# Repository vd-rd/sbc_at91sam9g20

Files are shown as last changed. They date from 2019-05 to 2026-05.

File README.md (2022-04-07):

# Microchip AT91SAM9G20

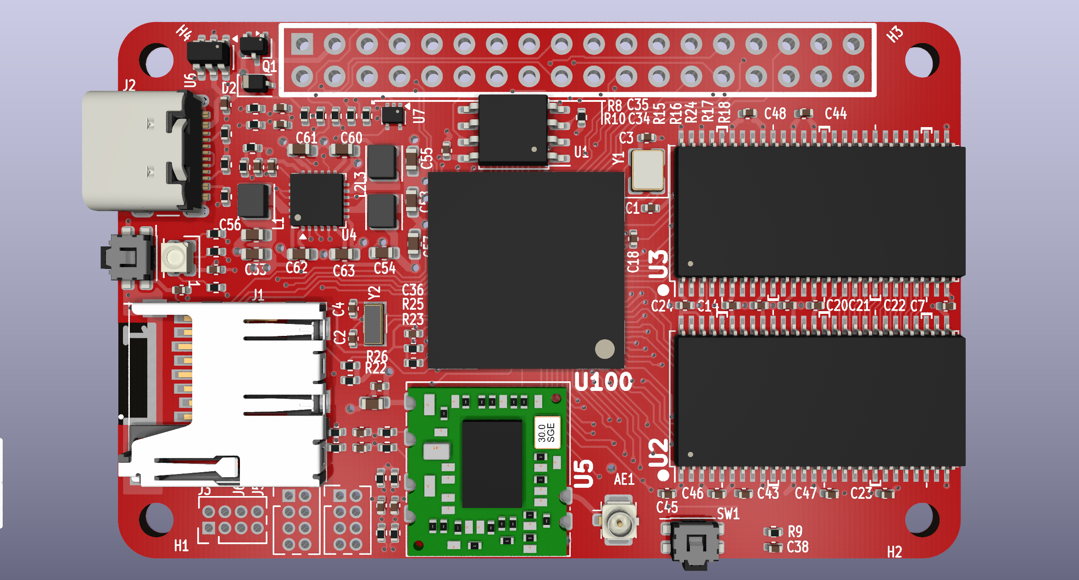
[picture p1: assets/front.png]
board_render


## Description
 The follow-up to my previous [SBC based on AT91SAM9260](https://github.com/vd-rd/sbc_at91sam9260), enhancing the board specs in computing power and flexibility. The board is smaller 60x40mm now (SAM9260 was 80x40mm) while keeping the same amount of supported RAM and interfaces. AT91SAM9G20 boosts core speed to 400MHz and bus speed to 133MHz.
 
Board overview (draft):
[TBD]

### Features

| Characteristic | Description |
| --- | --- |
| Dimensions | 60mm x 40mm |
| Processor | AT91SAM9G20 - ARM926EJ @ 400MHz |
| Oscillators |  18.432MHz main clock, 32.768kHz RTC |
| RAM | SDRAM 128MB max (2x512Mbit modules) |
| Storage | microSD |
| USB | 1 microUSB client, 2 USB Host|
| Ethernet | RMII header |
| WiFi/BT | N/A |
| Supply | USB 5V, ACIN 5V |

Common interfaces such as I2C, SPI, UART and GPIO are exposed on the header.

### Building and flashing

Build U-Boot and Linux kernel + rootFS - TBD

Flash to SDCard - TBD

### Resources

You can find all necesary information to build or evaluate the module here:
   - [Fabrication files](https://github.com/vd-rd/sbc_alw_a13/releases)

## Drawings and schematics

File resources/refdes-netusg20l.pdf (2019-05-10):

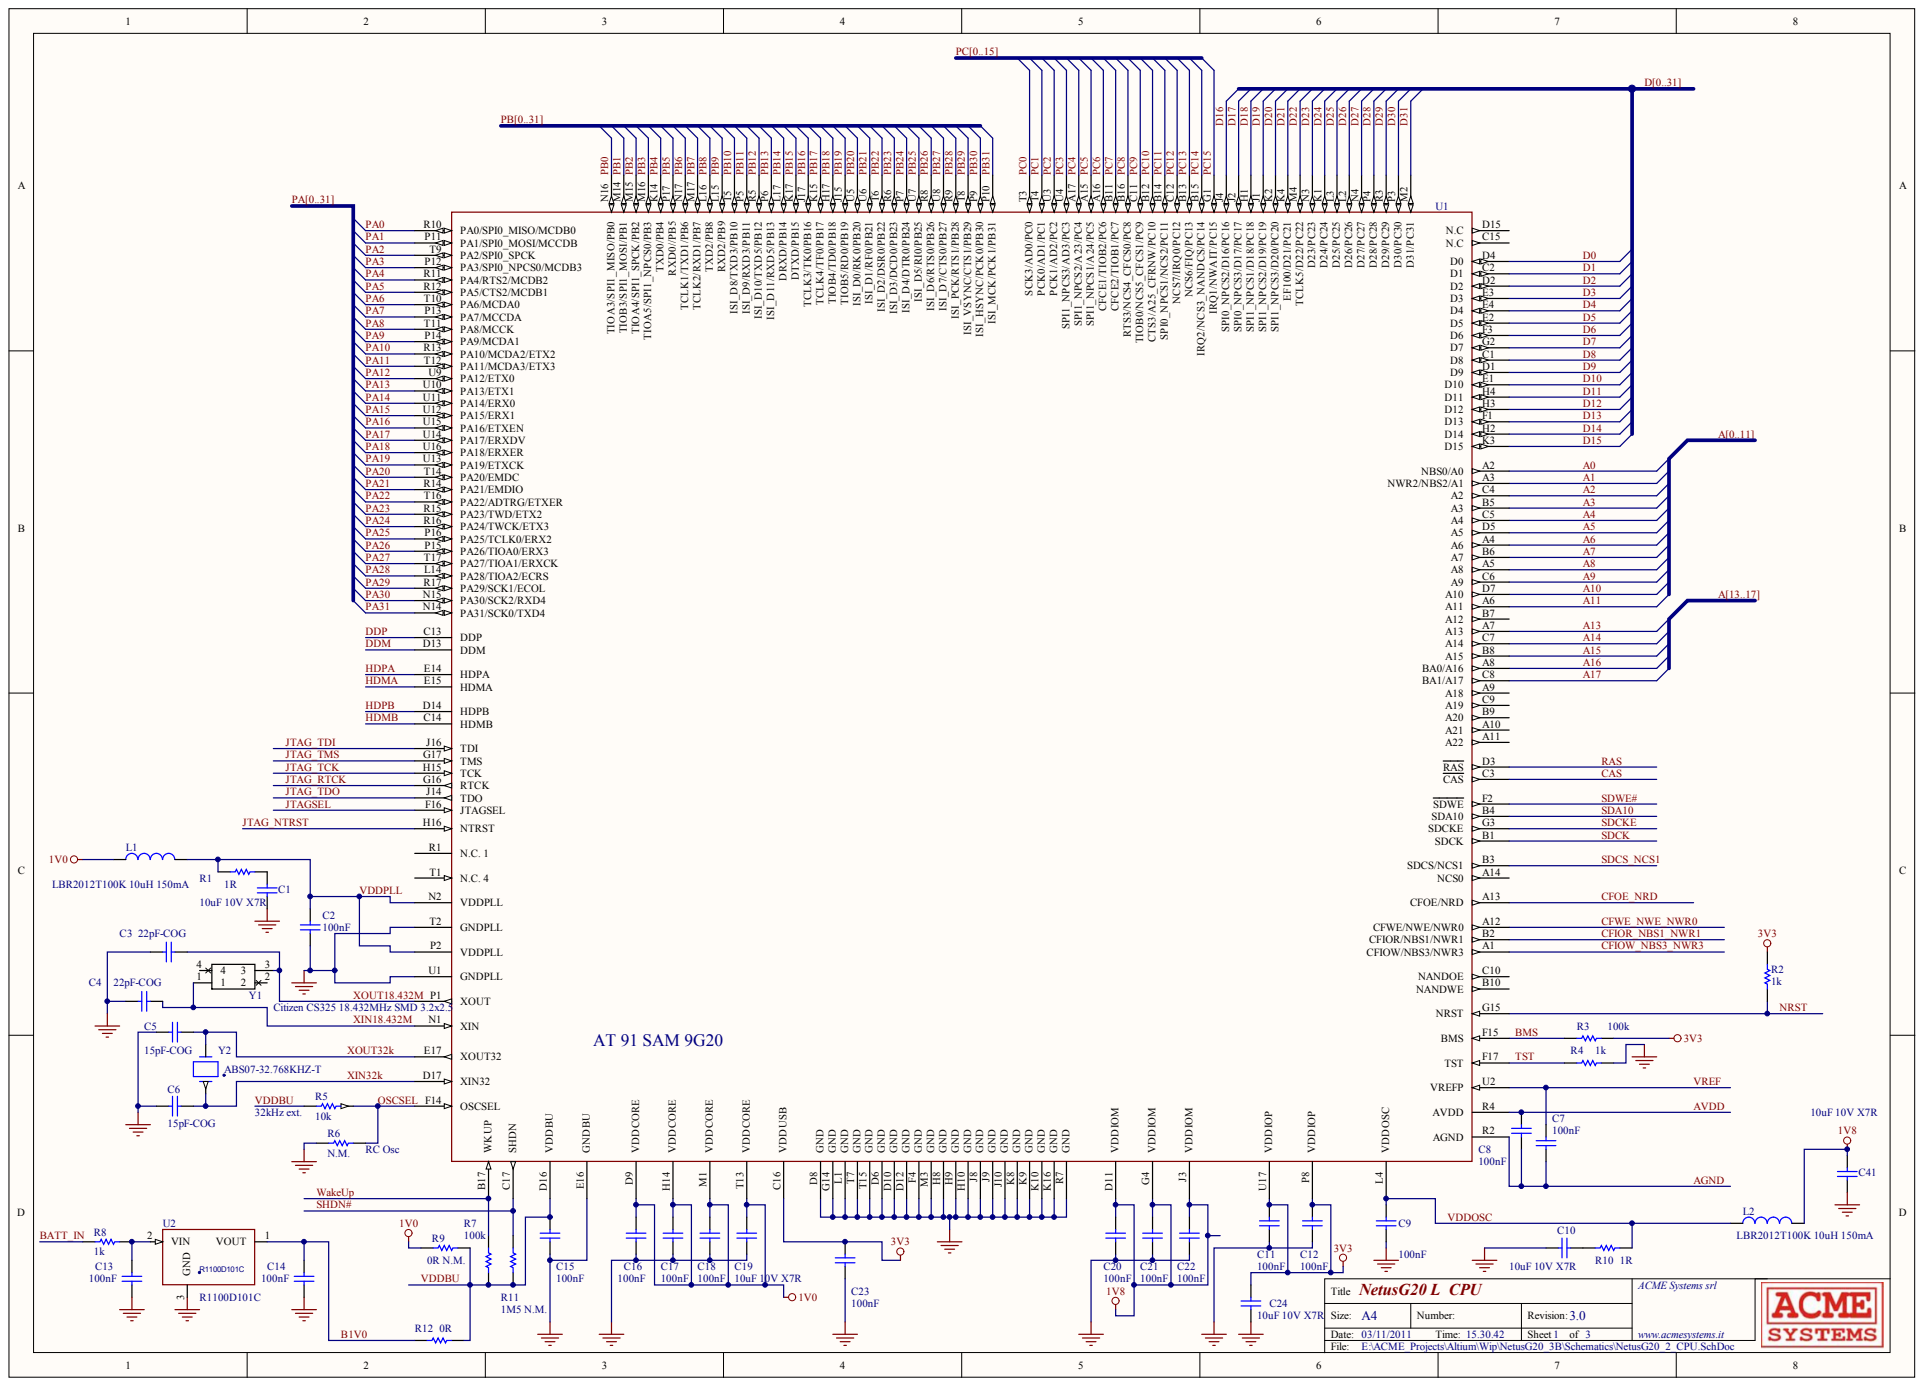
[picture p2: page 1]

3.2 x 2 . | 5 XIN N1

C5 15p | | | XOUT3 2 k | E 1 7

S 0 7 -3 2.7 6 8 KHZ -T XIN 3 2 k

VDDBU OSCSEL | F 1 4

C2 | | NetusG20 L CPU T itl | A CME Syste m s s r l www. a c esyst e ms.it

i z : A4 | Numb er: | Re v o n

Date ime . | | f

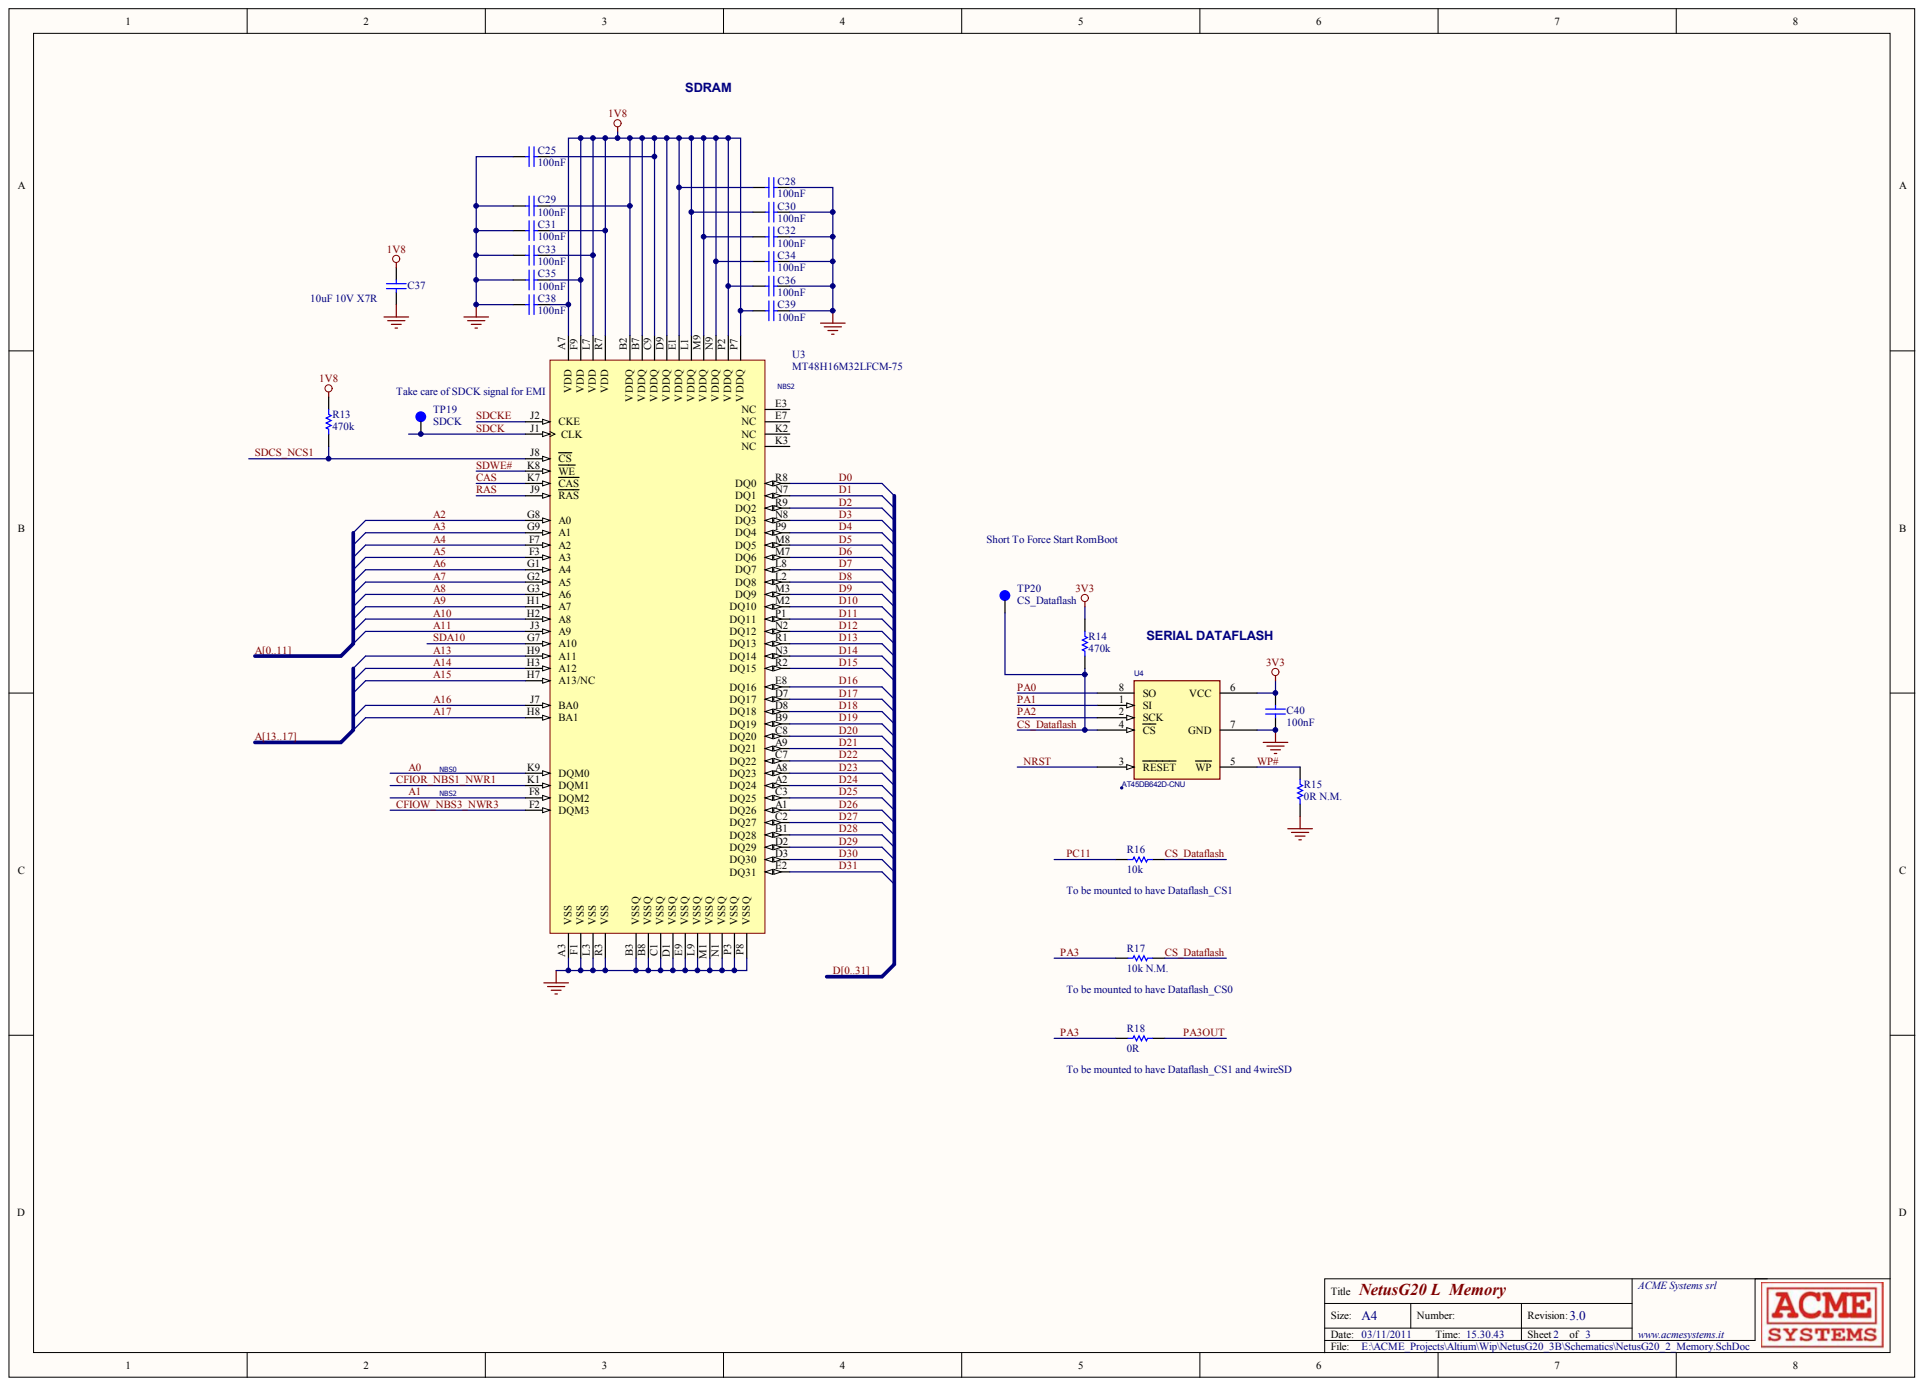
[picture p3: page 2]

VSSQ N1 VDDQ N9 VDDQ P2 VSSQ P3 VDDQ P7

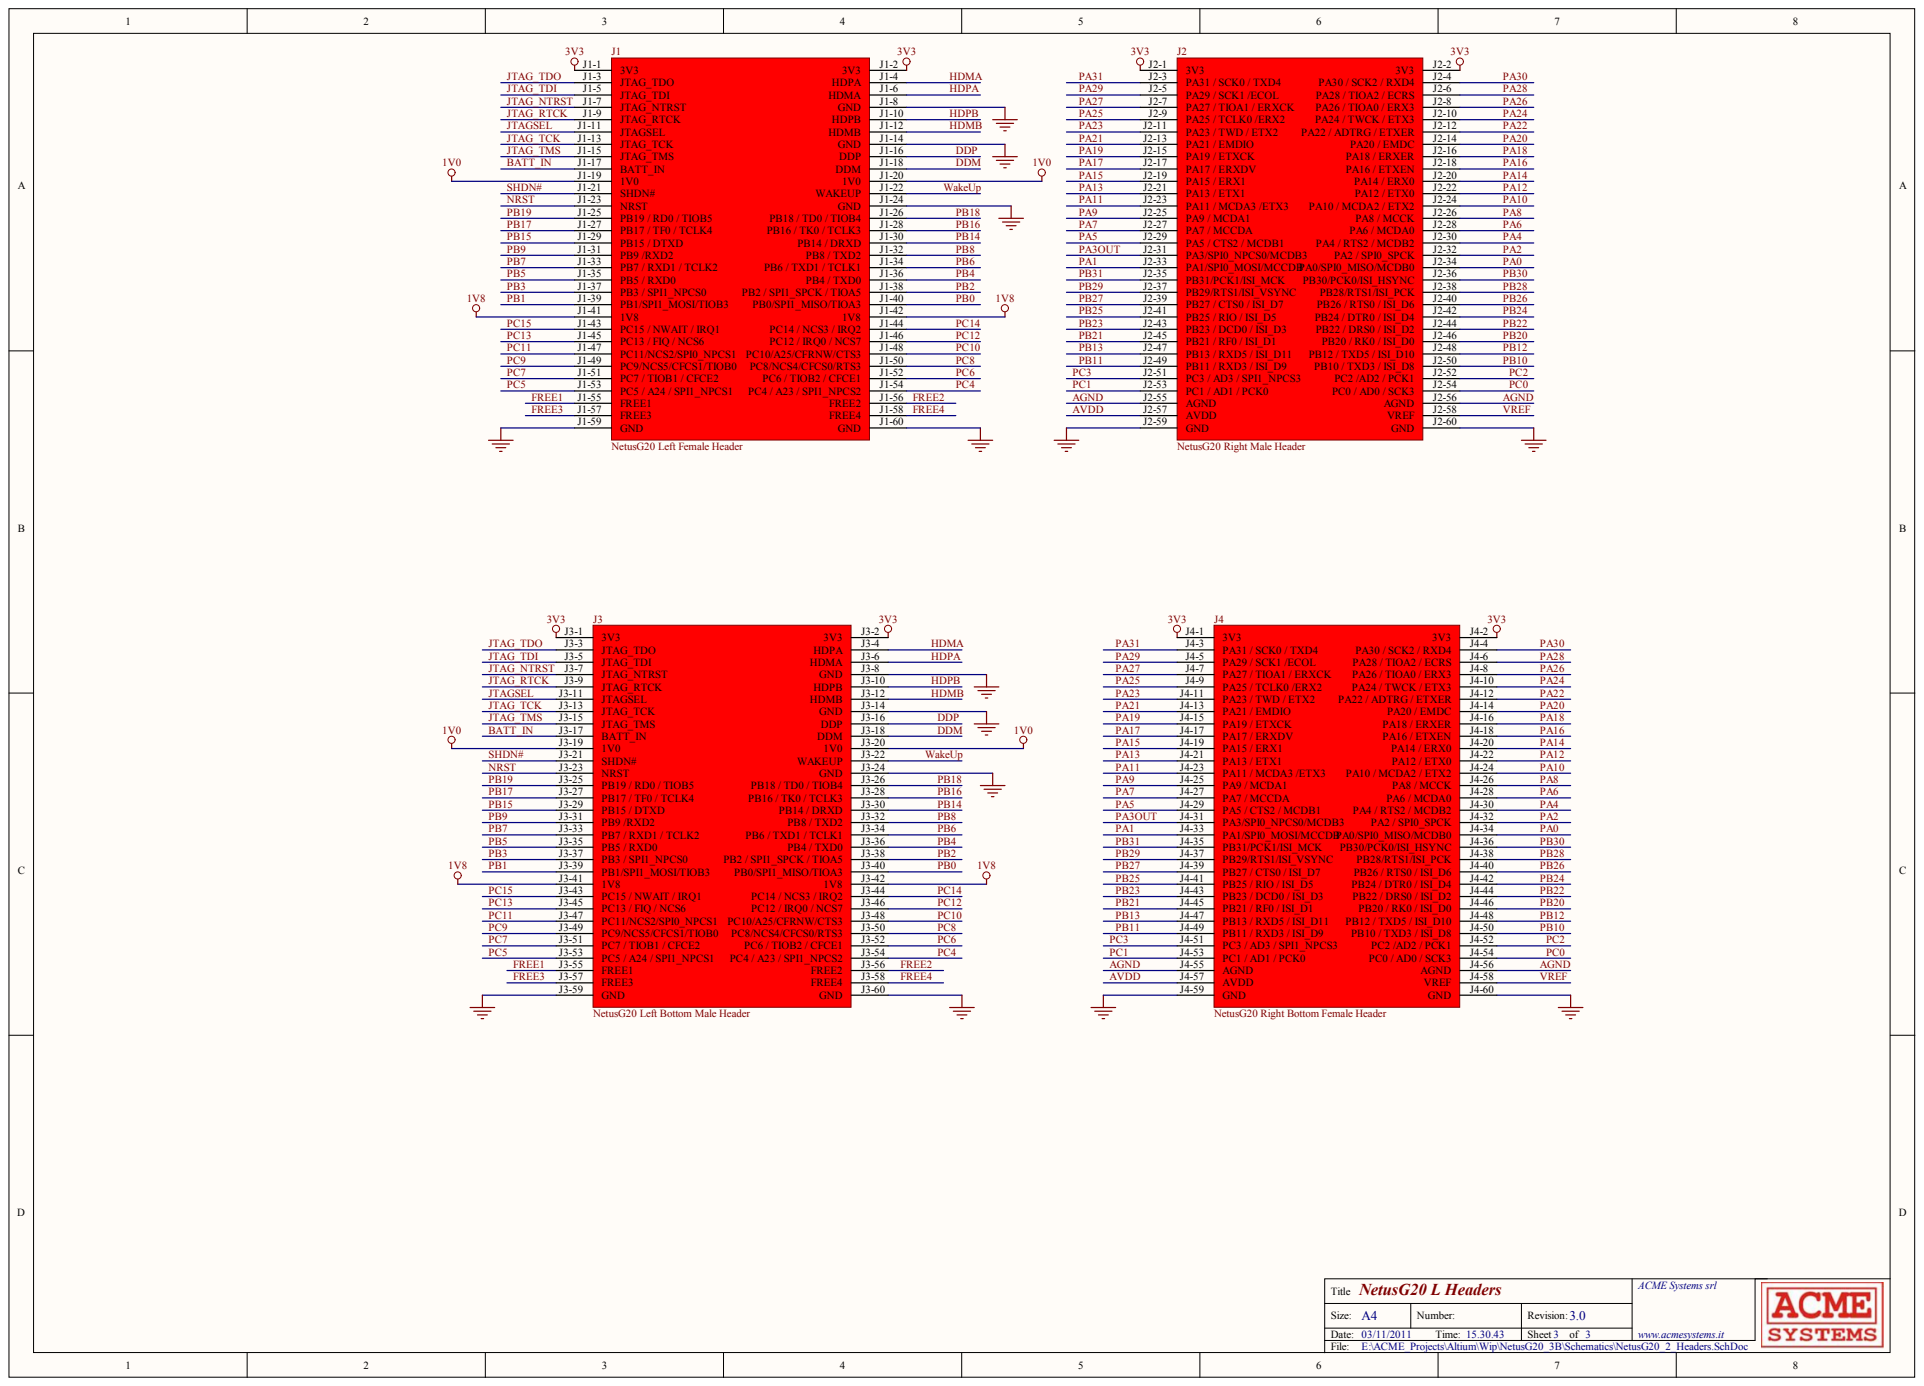
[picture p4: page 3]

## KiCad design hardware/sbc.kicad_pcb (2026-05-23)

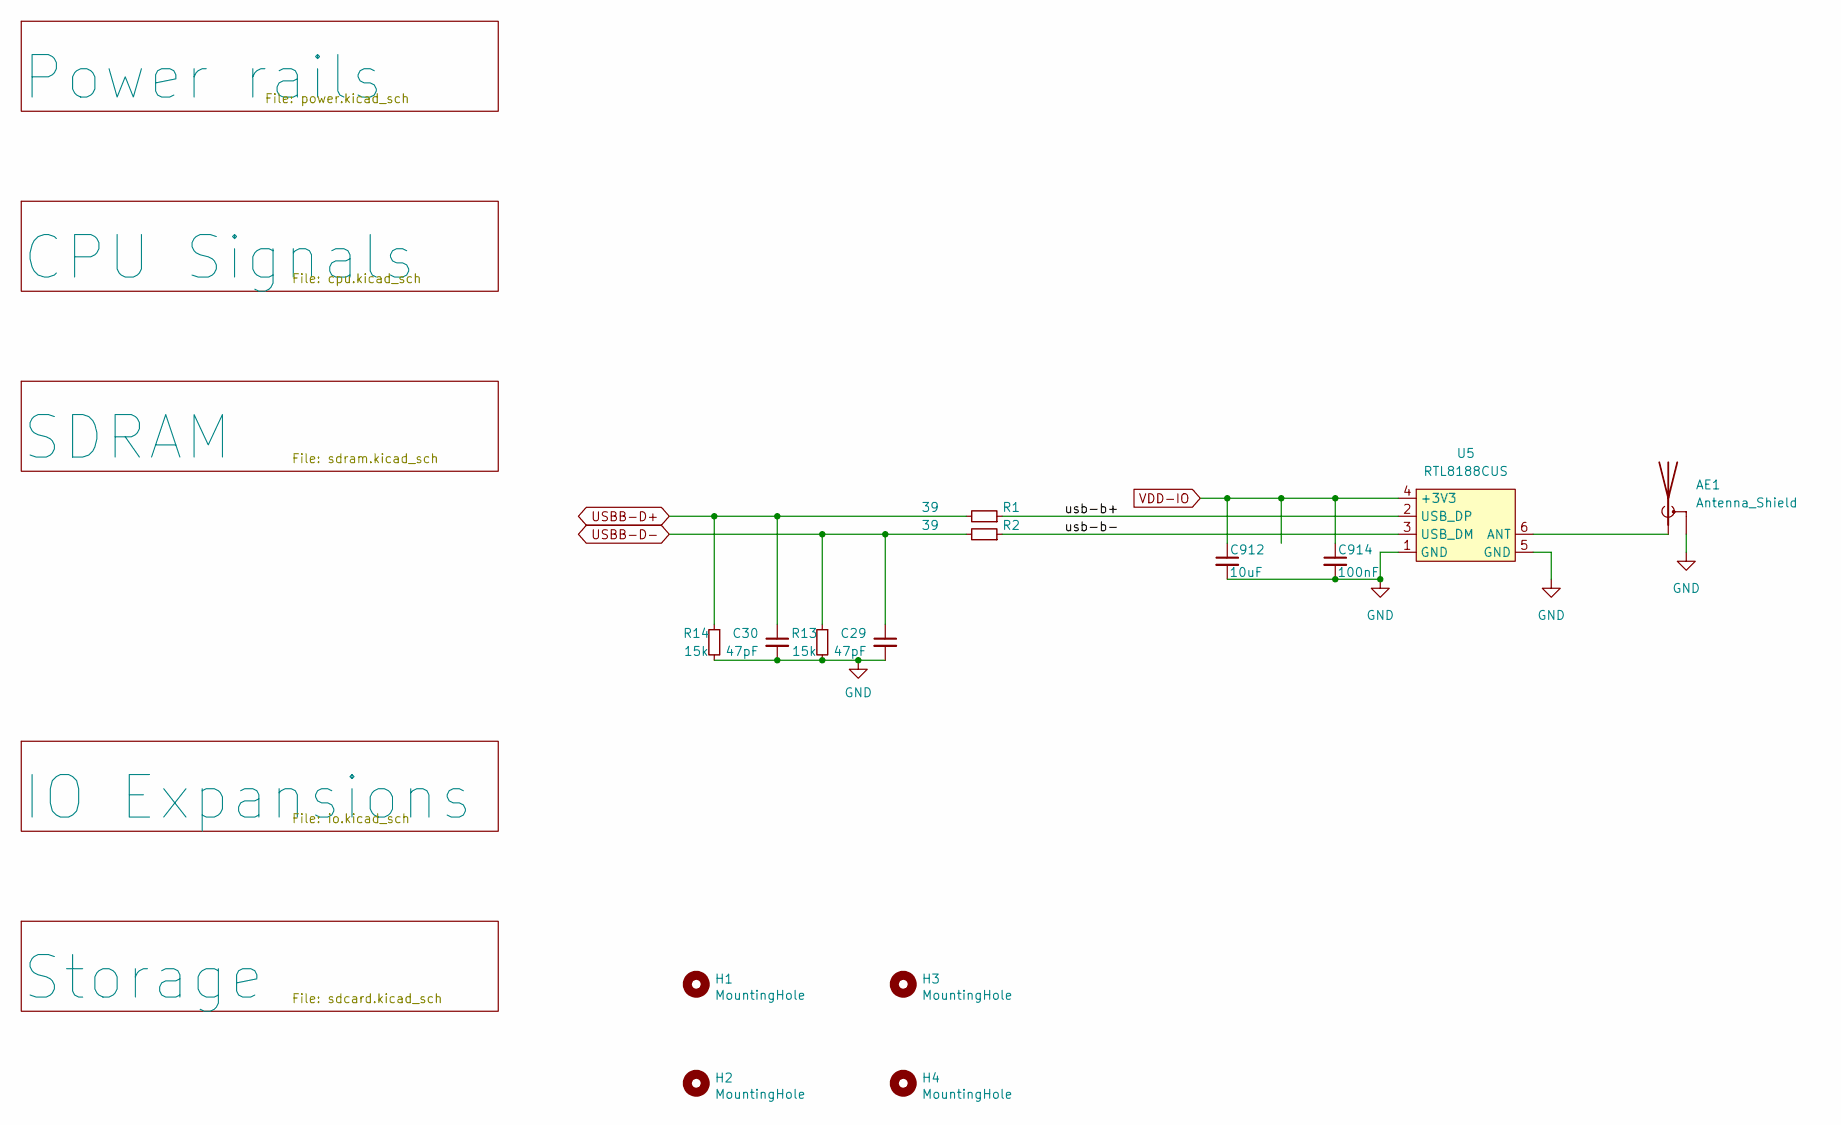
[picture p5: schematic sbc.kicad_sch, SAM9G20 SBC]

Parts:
AE1: Antenna_Shield; U.FL_Hirose_U.FL-R-SMT-1_Vertical
C29, C30: 47pF; C_0402_1005Metric
C912: 10uF; C_0603_1608Metric
C914: 100nF; C_0402_1005Metric
H1, H2, H3, H4: MountingHole; MountingHole_2.7mm_M2.5_DIN965
R1, R2: 39; R_0402_1005Metric
R13, R14: 15k; R_0402_1005Metric
U5: RTL8188CUS

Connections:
/usb-b+: R1.1, U5.2 (USB_DP)
/usb-b-: R2.1, U5.3 (USB_DM)
GND: AE1.2 (Shield), C29.2, C30.2, C912.2, C914.2, R13.2, R14.2, U5.1 (GND), U5.5 (GND); also elsewhere on the board
unnamed: AE1.1 (A), U5.6 (ANT)
USBB-D+: C30.1, R1.2, R14.1; also elsewhere on the board
USBB-D-: C29.1, R2.2, R13.1; also elsewhere on the board
VDD-IO: C912.1, C914.1, U5.4 (+3V3); also elsewhere on the board

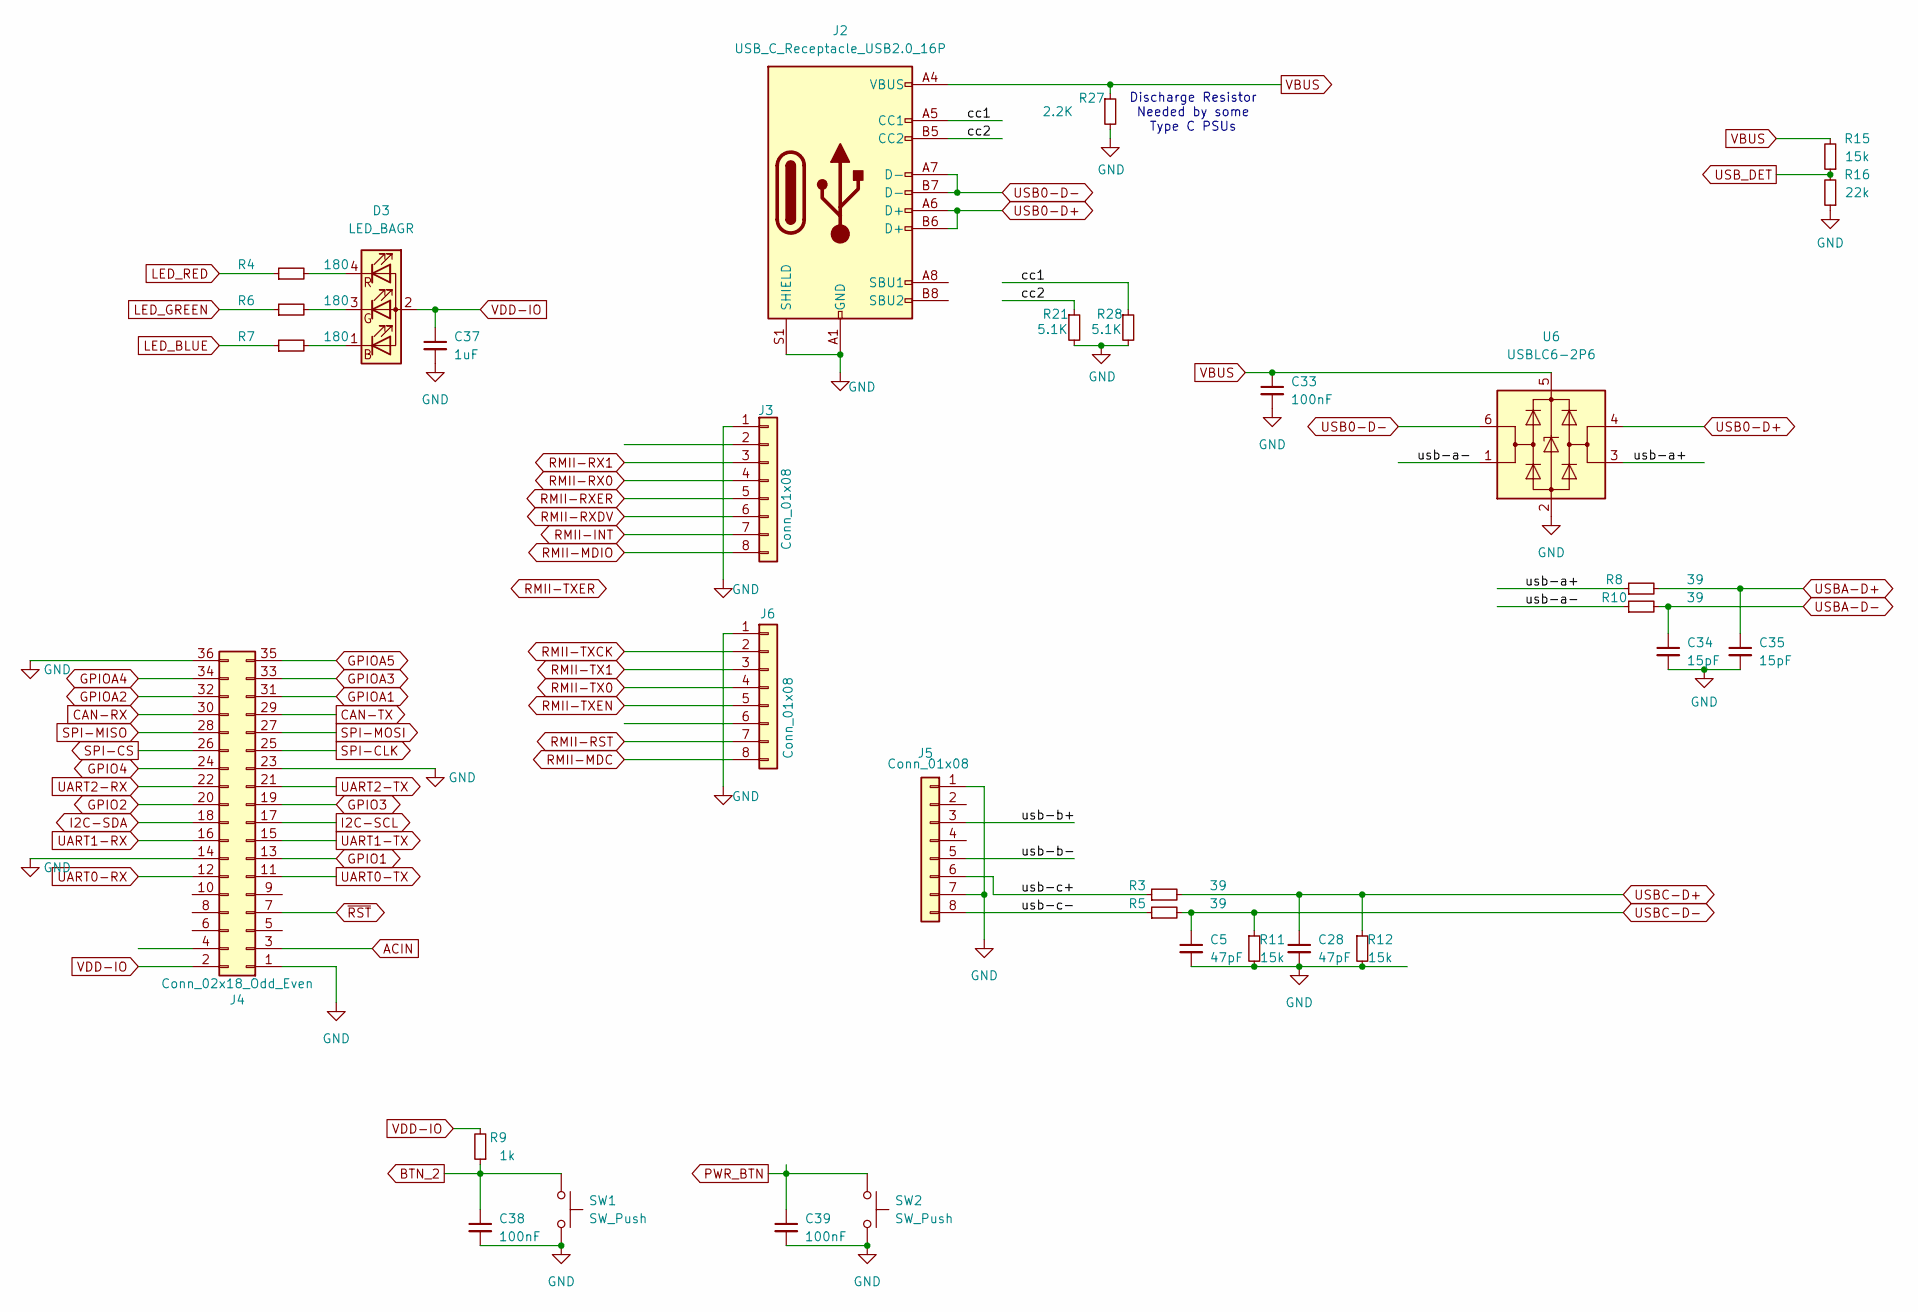
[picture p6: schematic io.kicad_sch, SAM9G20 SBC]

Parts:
C5, C28: 47pF; C_0402_1005Metric
C33, C38, C39: 100nF; C_0402_1005Metric
C34, C35: 15pF; C_0402_1005Metric
C37: 1uF; C_0402_1005Metric
D3: LED_BAGR; LED_RGB_Optosupply_OSTB0805C1E-A-0.8T
J2: USB_C_Receptacle_USB2.0_16P; USB_C_Receptacle_GCT_USB4105-xx-A_16P_TopMnt_Horizontal
J3, J5, J6: Conn_01x08; PinHeader_2x04_P1.27mm_Vertical
J4: Conn_02x18_Odd_Even; PinHeader_2x18_P2.54mm_Vertical
R3, R5, R8, R10: 39; R_0402_1005Metric
R4, R6, R7: 180; R_0402_1005Metric
R9: 1k; R_0402_1005Metric
R11, R12, R15: 15k; R_0402_1005Metric
R16: 22k; R_0402_1005Metric
R21, R28: 5.1K; R_0402_1005Metric; Part Description Resistor 2.2K M1005 1% 63mW
R27: 2.2K; R_0402_1005Metric; Part Description Resistor 2.2K M1005 1% 63mW
SW1, SW2: SW_Push; SW_SPST_EVQP7C
U6: USBLC6-2P6; SOT-23-6

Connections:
/IO Expansions/cc1: J2.A5 (CC1), R28.1
/IO Expansions/cc2: J2.B5 (CC2), R21.1
/IO Expansions/usb-a+: R8.1, U6.3 (I/O2)
/IO Expansions/usb-a-: R10.1, U6.1 (I/O1)
/IO Expansions/usb-b+: J5.3
/IO Expansions/usb-b-: J5.5
/IO Expansions/usb-c+: J5.6, R3.1
/IO Expansions/usb-c-: J5.8, R5.1
ACIN: J4.3; also elsewhere on the board
BTN_2: C38.1, R9.1, SW1.1; also elsewhere on the board
CAN-RX: J4.30
CAN-TX: J4.29
GND: C5.2, C28.2, C33.2, C34.2, C35.2, C37.2, C38.2, C39.2, J2.A1 (GND), J2.A12 (GND), J2.B1 (GND), J2.B12 (GND), J2.S1 (SHIELD), J3.1, J4.1, J4.14, J4.23, J4.36, J5.1, J5.7, J6.1, R11.2, R12.2, R16.1, R21.2, R27.2, R28.2, SW1.2, SW2.2, U6.2 (GND); also elsewhere on the board
GPIO1: J4.13; also elsewhere on the board
GPIO2: J4.20; also elsewhere on the board
GPIO3: J4.19; also elsewhere on the board
GPIO4: J4.24; also elsewhere on the board
GPIOA1: J4.31; also elsewhere on the board
GPIOA2: J4.32; also elsewhere on the board
GPIOA3: J4.33; also elsewhere on the board
GPIOA4: J4.34; also elsewhere on the board
GPIOA5: J4.35
I2C-SCL: J4.17; also elsewhere on the board
I2C-SDA: J4.18; also elsewhere on the board
LED_BLUE: R7.1; also elsewhere on the board
LED_GREEN: R6.1; also elsewhere on the board
LED_RED: R4.1; also elsewhere on the board
unnamed: D3.1 (BK), R7.2
unnamed: D3.3 (GK), R6.2
unnamed: D3.4 (RK), R4.2
PWR_BTN: C39.1, SW2.1; also elsewhere on the board
RMII-INT: J3.7
RMII-MDC: J6.8; also elsewhere on the board
RMII-MDIO: J3.8; also elsewhere on the board
RMII-RST: J6.7
RMII-RX0: J3.4; also elsewhere on the board
RMII-RX1: J3.3; also elsewhere on the board
RMII-RXDV: J3.6; also elsewhere on the board
RMII-RXER: J3.5; also elsewhere on the board
RMII-TX0: J6.4; also elsewhere on the board
RMII-TX1: J6.3; also elsewhere on the board
RMII-TXCK: J6.2; also elsewhere on the board
RMII-TXEN: J6.5; also elsewhere on the board
SPI-CLK: J4.25; also elsewhere on the board
SPI-CS: J4.26; also elsewhere on the board
SPI-MISO: J4.28; also elsewhere on the board
SPI-MOSI: J4.27; also elsewhere on the board
UART0-RX: J4.12; also elsewhere on the board
UART0-TX: J4.11; also elsewhere on the board
UART1-RX: J4.16; also elsewhere on the board
UART1-TX: J4.15; also elsewhere on the board
UART2-RX: J4.22; also elsewhere on the board
UART2-TX: J4.21; also elsewhere on the board
USB0-D+: J2.A6 (D+), J2.B6 (D+), U6.4 (I/O2)
USB0-D-: J2.A7 (D-), J2.B7 (D-), U6.6 (I/O1)
USBA-D+: C35.1, R8.2; also elsewhere on the board
USBA-D-: C34.1, R10.2; also elsewhere on the board
USBC-D+: C28.1, R3.2, R12.1; also elsewhere on the board
USBC-D-: C5.1, R5.2, R11.1; also elsewhere on the board
USB_DET: R15.1, R16.2; also elsewhere on the board
VBUS: C33.1, J2.A4 (VBUS), J2.A9 (VBUS), J2.B4 (VBUS), J2.B9 (VBUS), R15.2, R27.1, U6.5 (VBUS); also elsewhere on the board
VDD-IO: C37.1, D3.2 (A), J4.2, R9.2; also elsewhere on the board
~RST: J4.7; also elsewhere on the board

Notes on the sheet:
Discharge Resistor Needed by some Type C PSUs

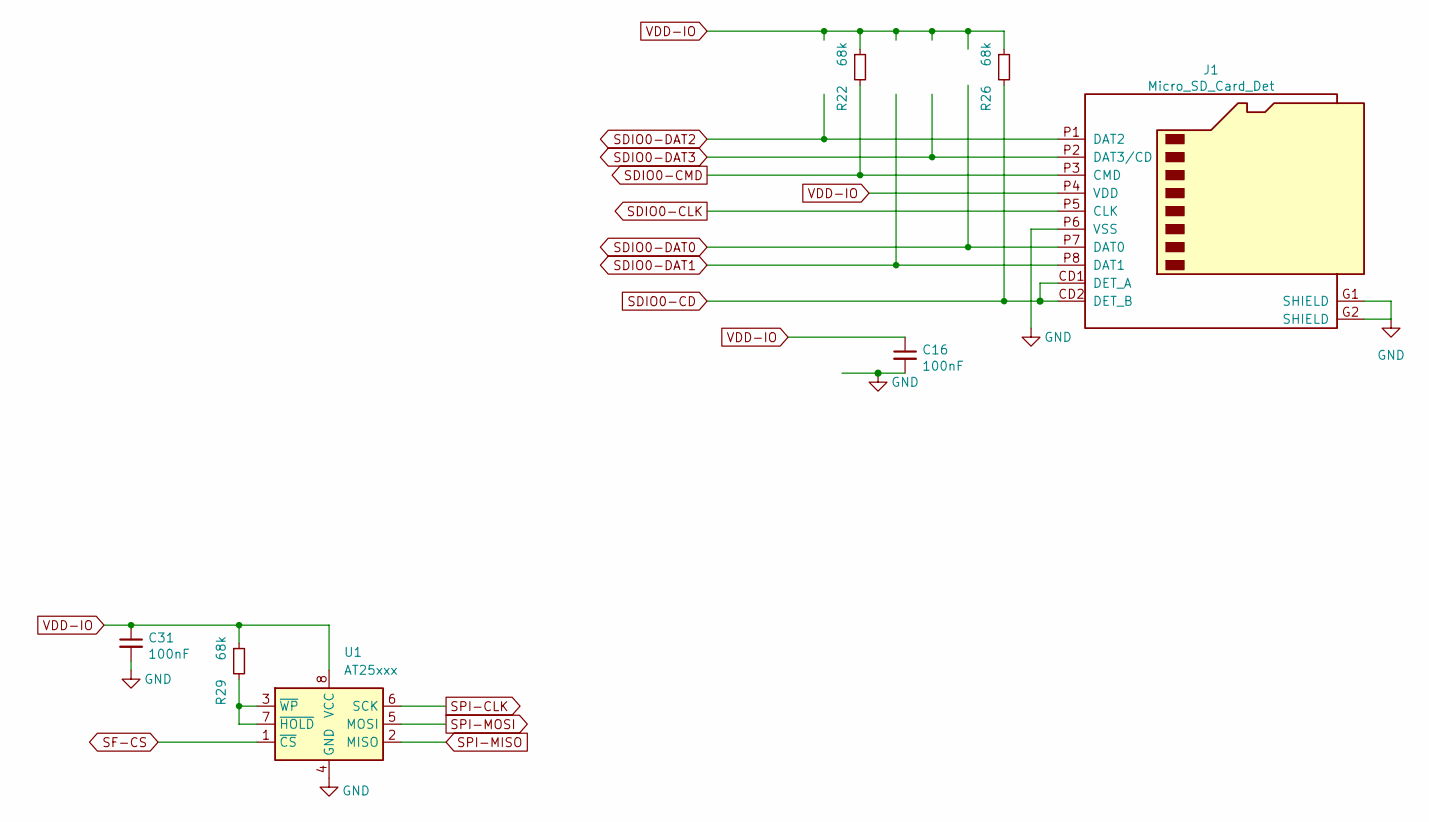
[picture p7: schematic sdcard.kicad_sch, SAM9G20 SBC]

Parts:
C16, C31: 100nF; C_0402_1005Metric
J1: Micro_SD_Card_Det; MEM20610118800A
R22, R26, R29: 68k; R_0402_1005Metric
U1: AT25xxx; SOIC-8_5.23x5.23mm_P1.27mm

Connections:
GND: C16.2, C31.2, J1.G1 (SHIELD), J1.G2 (SHIELD), J1.P6 (VSS), U1.4 (GND); also elsewhere on the board
unnamed: R29.2, U1.3 (~WP), U1.7 (~HOLD)
SDIO0-CD: J1.CD1 (DET_A), J1.CD2 (DET_B), R26.2; also elsewhere on the board
SDIO0-CLK: J1.P5 (CLK); also elsewhere on the board
SDIO0-CMD: J1.P3 (CMD), R22.2; also elsewhere on the board
SDIO0-DAT0: J1.P7 (DAT0); also elsewhere on the board
SDIO0-DAT1: J1.P8 (DAT1); also elsewhere on the board
SDIO0-DAT2: J1.P1 (DAT2); also elsewhere on the board
SDIO0-DAT3: J1.P2 (DAT3/CD); also elsewhere on the board
SF-CS: U1.1 (~CS); also elsewhere on the board
SPI-CLK: U1.6 (SCK); also elsewhere on the board
SPI-MISO: U1.2 (MISO); also elsewhere on the board
SPI-MOSI: U1.5 (MOSI); also elsewhere on the board
VDD-IO: C16.1, C31.1, J1.P4 (VDD), R22.1, R26.1, R29.1, U1.8 (VCC); also elsewhere on the board

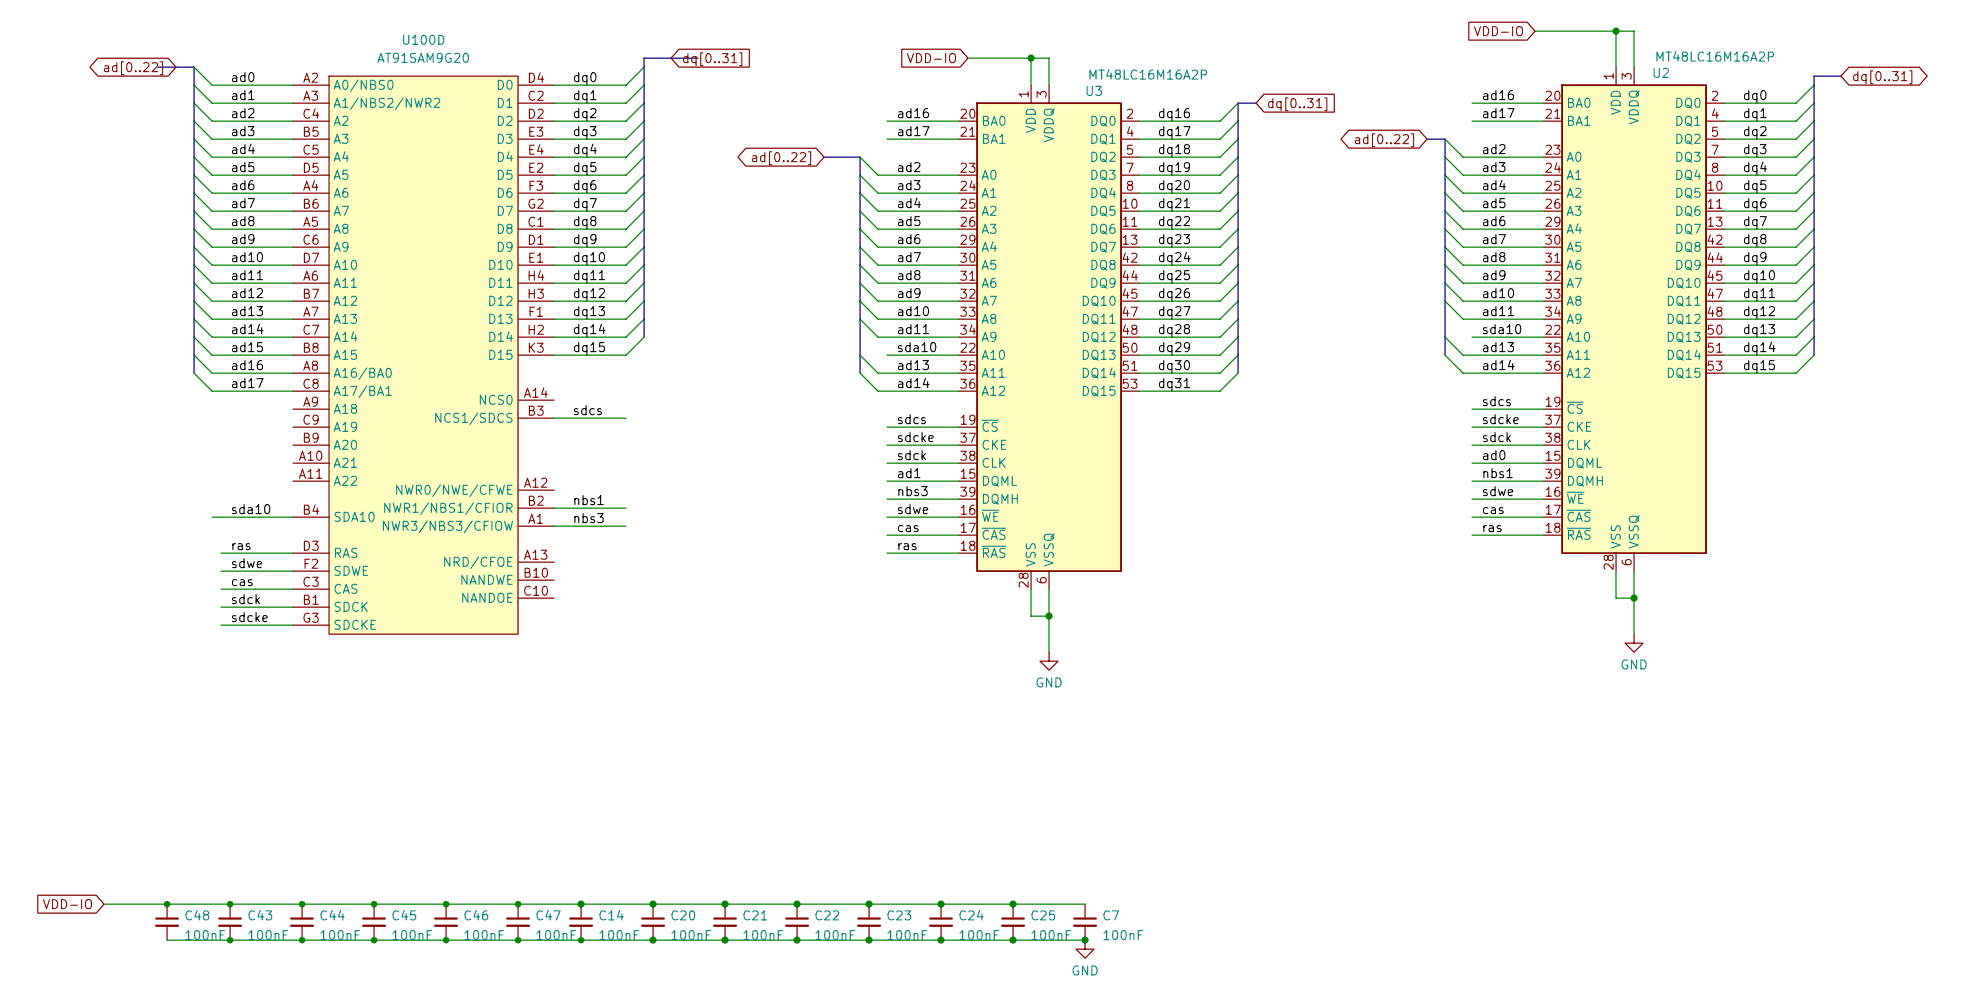
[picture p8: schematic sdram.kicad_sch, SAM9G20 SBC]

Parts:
C7, C14, C20, C21, C22, C23, C24, C25, C43, C44, C45, C46, C47, C48: 100nF; C_0402_1005Metric
U2, U3: MT48LC16M16A2P; TSOP-II-54_22.2x10.16mm_P0.8mm
U100: AT91SAM9G20; AT91SAM9G10

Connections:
/SDRAM/cas: U2.17 (~CAS), U3.17 (~CAS), U100.C3 (CAS)
/SDRAM/nbs1: U2.39 (DQMH), U100.B2 (NWR1/NBS1/CFIOR)
/SDRAM/nbs3: U3.39 (DQMH), U100.A1 (NWR3/NBS3/CFIOW)
/SDRAM/ras: U2.18 (~RAS), U3.18 (~RAS), U100.D3 (RAS)
/SDRAM/sda10: U2.22 (A10), U3.22 (A10), U100.B4 (SDA10)
/SDRAM/sdck: U2.38 (CLK), U3.38 (CLK), U100.B1 (SDCK)
/SDRAM/sdcke: U2.37 (CKE), U3.37 (CKE), U100.G3 (SDCKE)
/SDRAM/sdcs: U2.19 (~CS), U3.19 (~CS), U100.B3 (NCS1/SDCS)
/SDRAM/sdwe: U2.16 (~WE), U3.16 (~WE), U100.F2 (SDWE)
GND: C7.2, C14.2, C20.2, C21.2, C22.2, C23.2, C24.2, C25.2, C43.2, C44.2, C45.2, C46.2, C47.2, C48.2, U2.6 (VSSQ), U2.12 (VSSQ), U2.28 (VSS), U2.41 (VSS), U2.46 (VSSQ), U2.52 (VSSQ), U2.54 (VSS), U3.6 (VSSQ), U3.12 (VSSQ), U3.28 (VSS), U3.41 (VSS), U3.46 (VSSQ), U3.52 (VSSQ), U3.54 (VSS); also elsewhere on the board
VDD-IO: C7.1, C14.1, C20.1, C21.1, C22.1, C23.1, C24.1, C25.1, C43.1, C44.1, C45.1, C46.1, C47.1, C48.1, U2.1 (VDD), U2.3 (VDDQ), U2.9 (VDDQ), U2.14 (VDD), U2.27 (VDD), U2.43 (VDDQ), U2.49 (VDDQ), U3.1 (VDD), U3.3 (VDDQ), U3.9 (VDDQ), U3.14 (VDD), U3.27 (VDD), U3.43 (VDDQ), U3.49 (VDDQ); also elsewhere on the board
ad0: U2.15 (DQML), U100.A2 (A0/NBS0)
ad1: U3.15 (DQML), U100.A3 (A1/NBS2/NWR2)
ad2: U2.23 (A0), U3.23 (A0), U100.C4 (A2)
ad3: U2.24 (A1), U3.24 (A1), U100.B5 (A3)
ad4: U2.25 (A2), U3.25 (A2), U100.C5 (A4)
ad5: U2.26 (A3), U3.26 (A3), U100.D5 (A5)
ad6: U2.29 (A4), U3.29 (A4), U100.A4 (A6)
ad7: U2.30 (A5), U3.30 (A5), U100.B6 (A7)
ad8: U2.31 (A6), U3.31 (A6), U100.A5 (A8)
ad9: U2.32 (A7), U3.32 (A7), U100.C6 (A9)
ad10: U2.33 (A8), U3.33 (A8), U100.D7 (A10)
ad11: U2.34 (A9), U3.34 (A9), U100.A6 (A11)
ad12: U100.B7 (A12)
ad13: U2.35 (A11), U3.35 (A11), U100.A7 (A13)
ad14: U2.36 (A12), U3.36 (A12), U100.C7 (A14)
ad15: U100.B8 (A15)
ad16: U2.20 (BA0), U3.20 (BA0), U100.A8 (A16/BA0)
ad17: U2.21 (BA1), U3.21 (BA1), U100.C8 (A17/BA1)
dq0: U2.2 (DQ0), U100.D4 (D0)
dq1: U2.4 (DQ1), U100.C2 (D1)
dq2: U2.5 (DQ2), U100.D2
dq3: U2.7 (DQ3), U100.E3 (D3)
dq4: U2.8 (DQ4), U100.E4 (D4)
dq5: U2.10 (DQ5), U100.E2 (D5)
dq6: U2.11 (DQ6), U100.F3 (D6)
dq7: U2.13 (DQ7), U100.G2 (D7)
dq8: U2.42 (DQ8), U100.C1 (D8)
dq9: U2.44 (DQ9), U100.D1 (D9)
dq10: U2.45 (DQ10), U100.E1 (D10)
dq11: U2.47 (DQ11), U100.H4 (D11)
dq12: U2.48 (DQ12), U100.H3 (D12)
dq13: U2.50 (DQ13), U100.F1 (D13)
dq14: U2.51 (DQ14), U100.H2 (D14)
dq15: U2.53 (DQ15), U100.K3 (D15)
dq16: U3.2 (DQ0); also elsewhere on the board
dq17: U3.4 (DQ1); also elsewhere on the board
dq18: U3.5 (DQ2); also elsewhere on the board
dq19: U3.7 (DQ3); also elsewhere on the board
dq20: U3.8 (DQ4); also elsewhere on the board
dq21: U3.10 (DQ5); also elsewhere on the board
dq22: U3.11 (DQ6); also elsewhere on the board
dq23: U3.13 (DQ7); also elsewhere on the board
dq24: U3.42 (DQ8); also elsewhere on the board
dq25: U3.44 (DQ9); also elsewhere on the board
dq26: U3.45 (DQ10); also elsewhere on the board
dq27: U3.47 (DQ11); also elsewhere on the board
dq28: U3.48 (DQ12); also elsewhere on the board
dq29: U3.50 (DQ13); also elsewhere on the board
dq30: U3.51 (DQ14); also elsewhere on the board
dq31: U3.53 (DQ15); also elsewhere on the board

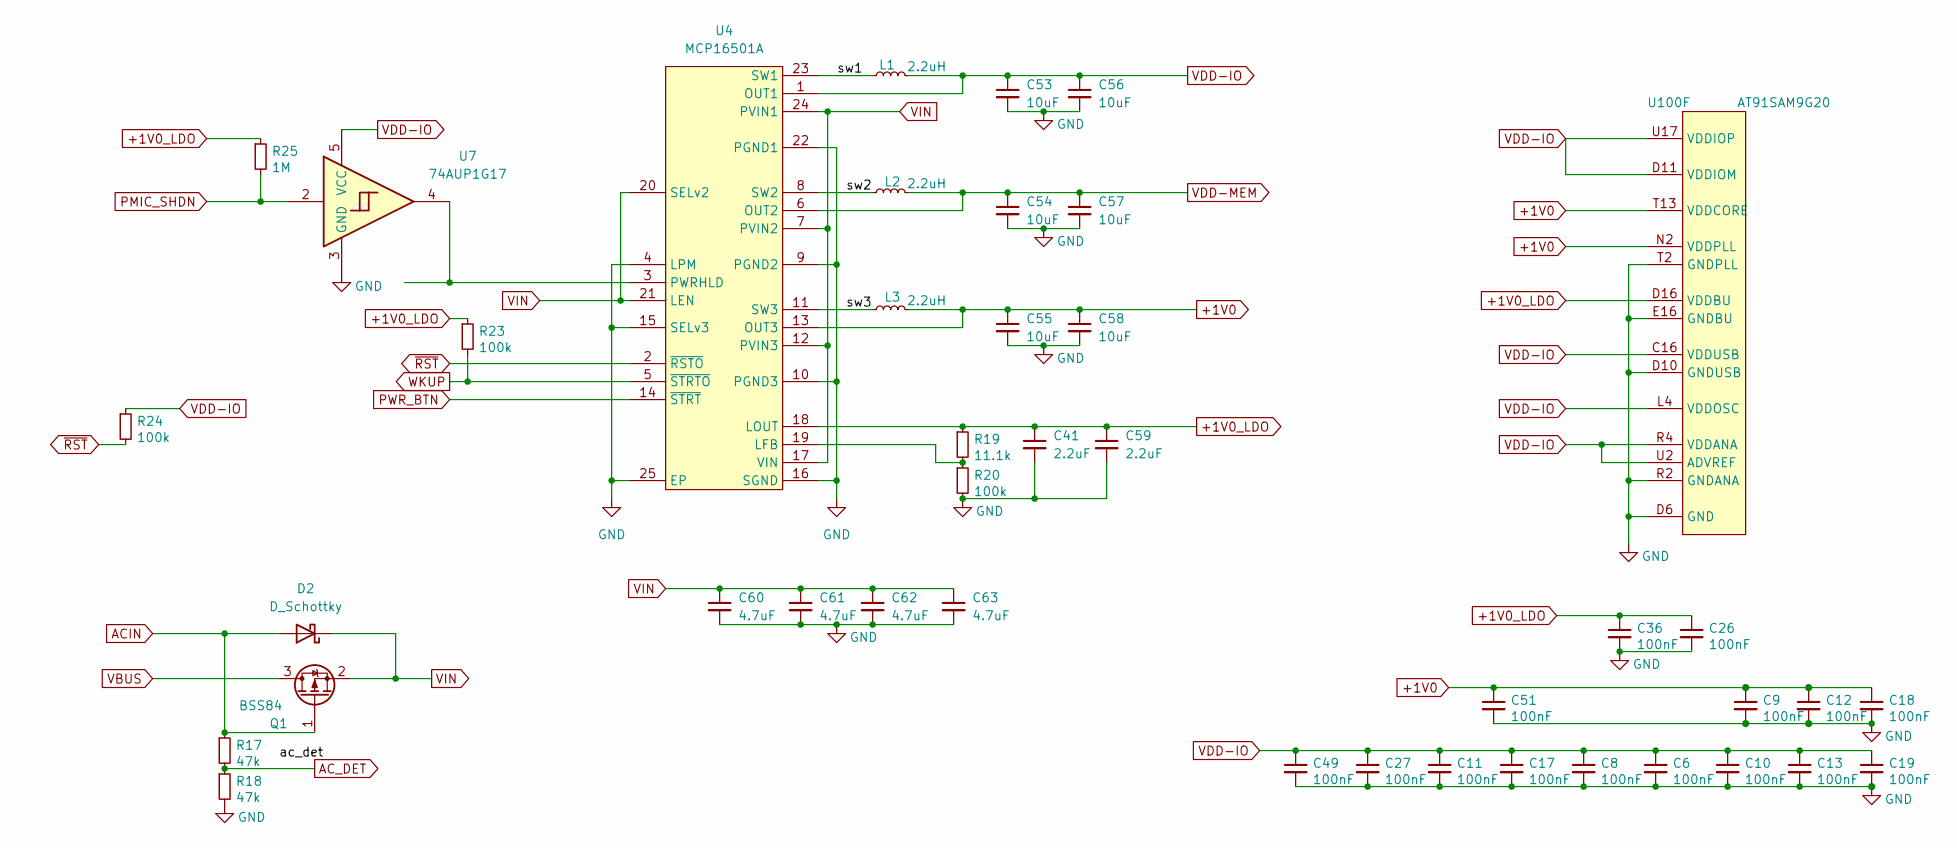
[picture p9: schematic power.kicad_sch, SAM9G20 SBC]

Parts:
C6, C8, C9, C10, C11, C12, C13, C17, C18, C19, C26, C27, C36, C49, C51: 100nF; C_0402_1005Metric
C41, C59: 2.2uF; C_0402_1005Metric
C53, C54, C55, C56, C57, C58: 10uF; C_0603_1608Metric
C60, C61, C62, C63: 4.7uF; C_0603_1608Metric
D2: D_Schottky; D_SOD-323
L1, L2, L3: 2.2uH; L_Wuerth_MAPI-2512
Q1: BSS84; SOT-323_SC-70
R17, R18: 47k; R_0402_1005Metric
R19: 11.1k; R_0402_1005Metric
R20, R23, R24: 100k; R_0402_1005Metric
R25: 1M; R_0402_1005Metric
U4: MCP16501A; QFN-24-1EP_4x4mm_P0.5mm_EP2.7x2.7mm_ThermalVias
U7: 74AUP1G17; Texas_R-PDSO-N5_DRL-5
U100: AT91SAM9G20; AT91SAM9G10

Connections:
+1V0: C9.1, C12.1, C18.1, C51.1, C55.1, C58.1, L3.2, U4.13 (OUT3), U100.D9 (VDDCORE), U100.H14 (VDDCORE), U100.M1 (VDDCORE), U100.N2 (VDDPLL), U100.P2 (VDDPLL), U100.T13 (VDDCORE)
+1V0_LDO: C26.1, C36.1, C41.1, C59.1, R19.1, R23.1, R25.1, U4.18 (LOUT), U100.D16 (VDDBU); also elsewhere on the board
/Power rails/sw1: L1.1, U4.23 (SW1)
/Power rails/sw2: L2.1, U4.8 (SW2)
/Power rails/sw3: L3.1, U4.11 (SW3)
ACIN: D2.2 (A), Q1.1 (G), R17.1; also elsewhere on the board
AC_DET: R17.2, R18.1; also elsewhere on the board
GND: C6.2, C8.2, C9.2, C10.2, C11.2, C12.2, C13.2, C17.2, C18.2, C19.2, C26.2, C27.2, C36.2, C41.2, C49.2, C51.2, C53.2, C54.2, C55.2, C56.2, C57.2, C58.2, C59.2, C60.2, C61.2, C62.2, C63.2, R18.2, R20.2, U4.4 (LPM), U4.9 (PGND2), U4.10 (PGND3), U4.15 (SELv3), U4.16 (SGND), U4.22 (PGND1), U4.25 (EP), U7.3 (GND), U100.D6 (GND), U100.D8 (GND), U100.D10 (GNDUSB), U100.D12 (GNDUSB), U100.E16 (GNDBU), U100.F4 (GND), U100.G14 (GND), U100.H8 (GND), U100.H9 (GND), U100.H10 (GND), U100.J8 (GND), U100.J9 (GND), U100.J10 (GND), U100.K8 (GND), U100.K9 (GND), U100.K10 (GND), U100.K16 (GND), U100.L1 (GND), U100.M3 (GND), U100.R2 (GNDANA), U100.R7 (GND), U100.T2 (GNDPLL), U100.T7 (GND), U100.T15 (GND), U100.U1 (GNDPLL); also elsewhere on the board
unnamed: R19.2, R20.1, U4.19 (LFB)
unnamed: U4.3 (PWRHLD), U7.4
PMIC_SHDN: R25.2, U7.2; also elsewhere on the board
PWR_BTN: U4.14 (~STRT); also elsewhere on the board
VBUS: Q1.3 (D); also elsewhere on the board
VDD-IO: C6.1, C8.1, C10.1, C11.1, C13.1, C17.1, C19.1, C27.1, C49.1, C53.1, C56.1, L1.2, R24.1, U4.1 (OUT1), U7.5 (VCC), U100.C16 (VDDUSB), U100.D11 (VDDIOM), U100.G4 (VDDIOM), U100.J3 (VDDIOM), U100.L4 (VDDOSC), U100.P8 (VDDIOP), U100.R4 (VDDANA), U100.U2 (ADVREF), U100.U17 (VDDIOP); also elsewhere on the board
VDD-MEM: C54.1, C57.1, L2.2, U4.6 (OUT2)
VIN: C60.1, C61.1, C62.1, C63.1, D2.1 (K), Q1.2 (S), U4.7 (PVIN2), U4.12 (PVIN3), U4.17 (VIN), U4.20 (SELv2), U4.21 (LEN), U4.24 (PVIN1)
WKUP: R23.2, U4.5 (~STRTO); also elsewhere on the board
~RST: R24.2, U4.2 (~RSTO); also elsewhere on the board

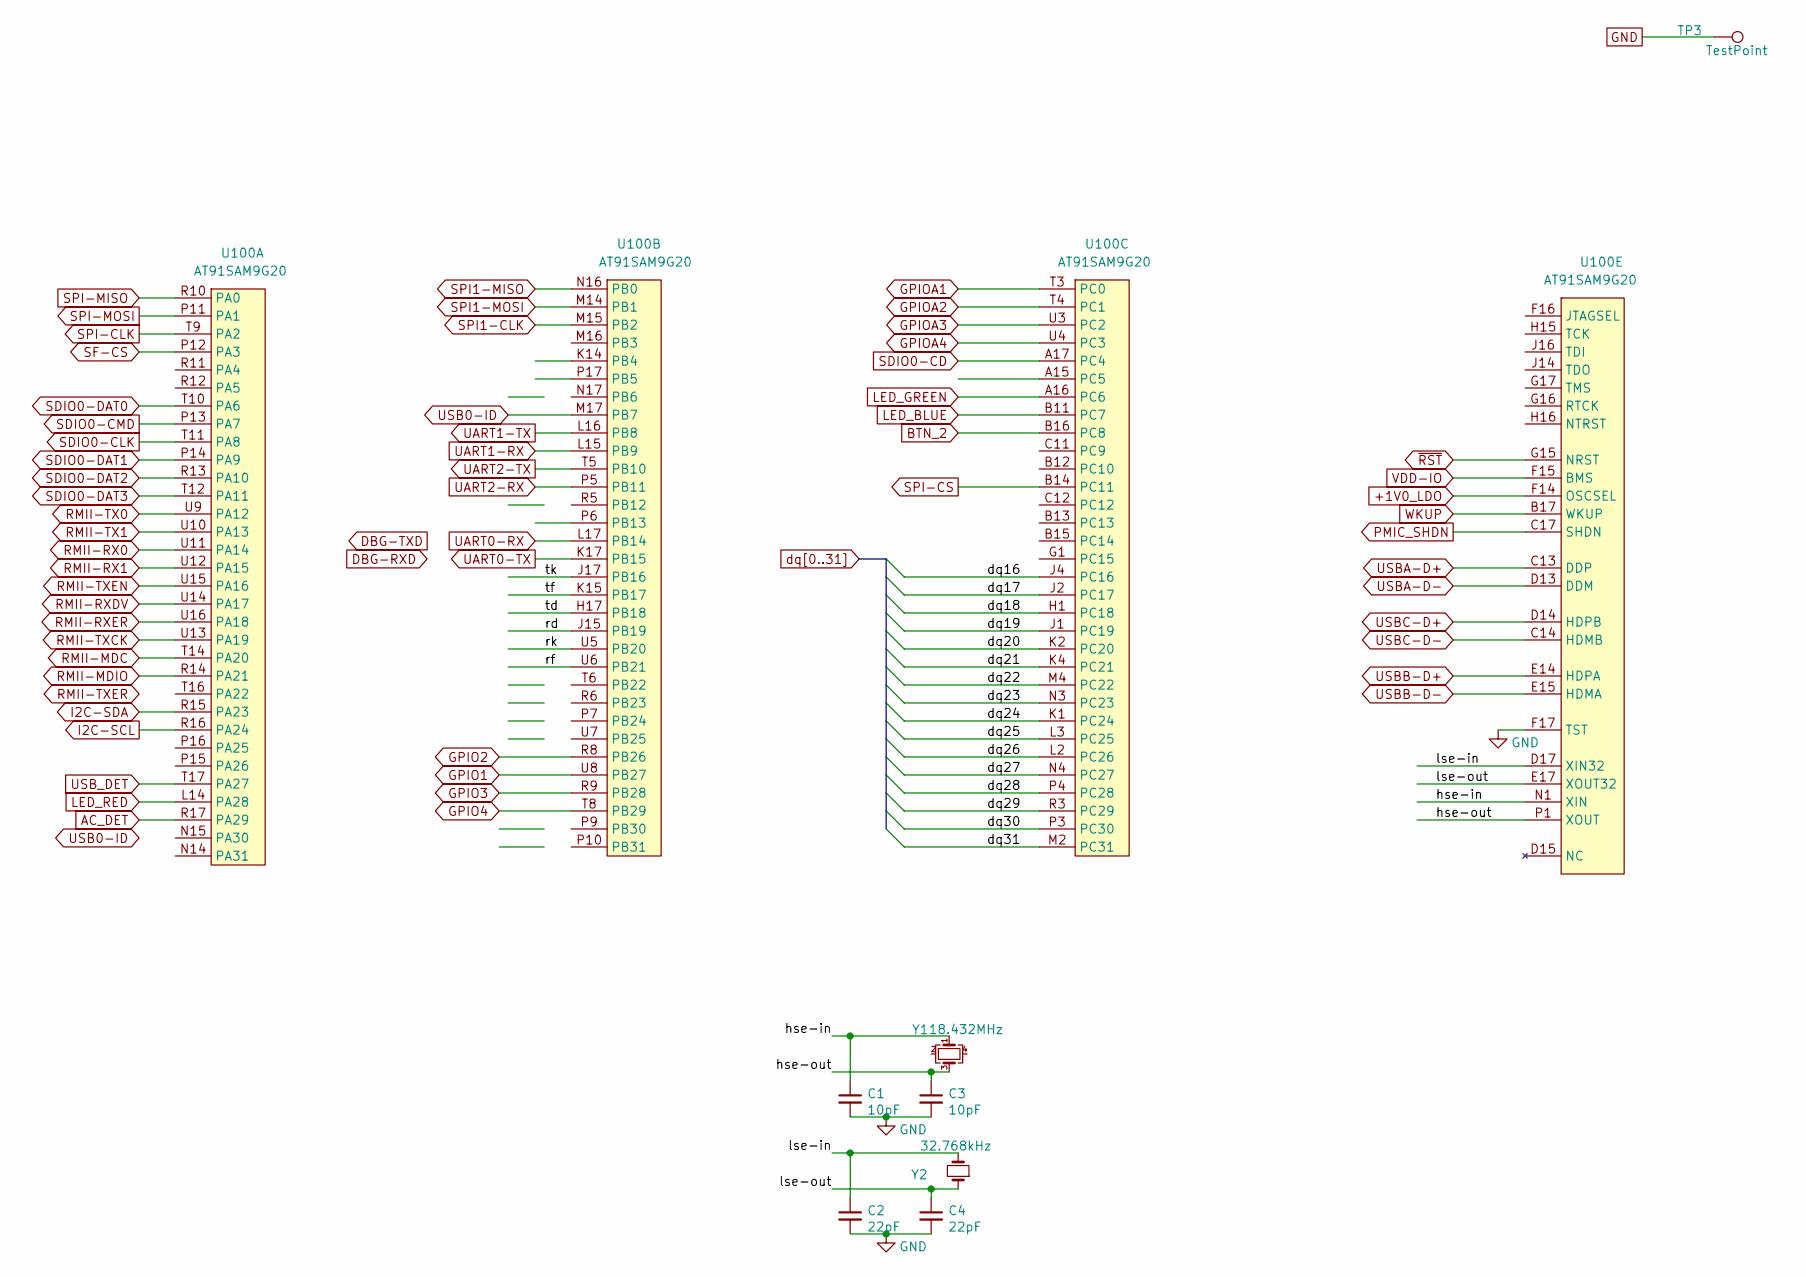
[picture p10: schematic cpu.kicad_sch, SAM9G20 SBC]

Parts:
C1, C3: 10pF; C_0402_1005Metric
C2, C4: 22pF; C_0402_1005Metric
TP3: TestPoint; TestPoint_Pad_D1.0mm
U100: AT91SAM9G20; AT91SAM9G10
Y1: 18.432MHz; Crystal_SMD_3225-4Pin_3.2x2.5mm
Y2: 32.768kHz; Crystal_SMD_3215-2Pin_3.2x1.5mm

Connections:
+1V0_LDO: U100.F14 (OSCSEL); also elsewhere on the board
/CPU Signals/hse-in: C1.1, U100.N1 (XIN), Y1.1
/CPU Signals/hse-out: C3.1, U100.P1 (XOUT), Y1.3
/CPU Signals/lse-in: C2.1, U100.D17 (XIN32), Y2.2
/CPU Signals/lse-out: C4.1, U100.E17 (XOUT32), Y2.1
/CPU Signals/rd: U100.J15 (PB19)
/CPU Signals/rf: U100.U6 (PB21)
/CPU Signals/rk: U100.U5 (PB20)
/CPU Signals/td: U100.H17 (PB18)
/CPU Signals/tf: U100.K15 (PB17)
/CPU Signals/tk: U100.J17 (PB16)
AC_DET: U100.R17 (PA29); also elsewhere on the board
BTN_2: U100.B16 (PC8); also elsewhere on the board
GND: C1.2, C2.2, C3.2, C4.2, TP3.1 (1_1), U100.F17 (TST); also elsewhere on the board
GPIO1: U100.U8 (PB27); also elsewhere on the board
GPIO2: U100.R8 (PB26); also elsewhere on the board
GPIO3: U100.R9 (PB28); also elsewhere on the board
GPIO4: U100.T8 (PB29); also elsewhere on the board
GPIOA1: U100.T3 (PC0); also elsewhere on the board
GPIOA2: U100.T4 (PC1); also elsewhere on the board
GPIOA3: U100.U3 (PC2); also elsewhere on the board
GPIOA4: U100.U4 (PC3); also elsewhere on the board
I2C-SCL: U100.R16 (PA24); also elsewhere on the board
I2C-SDA: U100.R15 (PA23); also elsewhere on the board
LED_BLUE: U100.B11 (PC7); also elsewhere on the board
LED_GREEN: U100.A16 (PC6); also elsewhere on the board
LED_RED: U100.L14 (PA28); also elsewhere on the board
PMIC_SHDN: U100.C17 (SHDN); also elsewhere on the board
RMII-MDC: U100.T14 (PA20); also elsewhere on the board
RMII-MDIO: U100.R14 (PA21); also elsewhere on the board
RMII-RX0: U100.U11 (PA14); also elsewhere on the board
RMII-RX1: U100.U12 (PA15); also elsewhere on the board
RMII-RXDV: U100.U14 (PA17); also elsewhere on the board
RMII-RXER: U100.U16 (PA18); also elsewhere on the board
RMII-TX0: U100.U9 (PA12); also elsewhere on the board
RMII-TX1: U100.U10 (PA13); also elsewhere on the board
RMII-TXCK: U100.U13 (PA19); also elsewhere on the board
RMII-TXEN: U100.U15 (PA16); also elsewhere on the board
SDIO0-CD: U100.A17 (PC4); also elsewhere on the board
SDIO0-CLK: U100.T11 (PA8); also elsewhere on the board
SDIO0-CMD: U100.P13 (PA7); also elsewhere on the board
SDIO0-DAT0: U100.T10 (PA6); also elsewhere on the board
SDIO0-DAT1: U100.P14 (PA9); also elsewhere on the board
SDIO0-DAT2: U100.R13 (PA10); also elsewhere on the board
SDIO0-DAT3: U100.T12 (PA11); also elsewhere on the board
SF-CS: U100.P12 (PA3); also elsewhere on the board
SPI1-CLK: U100.M15 (PB2)
SPI1-MISO: U100.N16 (PB0)
SPI1-MOSI: U100.M14 (PB1)
SPI-CLK: U100.T9 (PA2); also elsewhere on the board
SPI-CS: U100.B14 (PC11); also elsewhere on the board
SPI-MISO: U100.R10 (PA0); also elsewhere on the board
SPI-MOSI: U100.P11 (PA1); also elsewhere on the board
UART0-RX: U100.L17 (PB14); also elsewhere on the board
UART0-TX: U100.K17 (PB15); also elsewhere on the board
UART1-RX: U100.L15 (PB9); also elsewhere on the board
UART1-TX: U100.L16 (PB8); also elsewhere on the board
UART2-RX: U100.P5 (PB11); also elsewhere on the board
UART2-TX: U100.T5 (PB10); also elsewhere on the board
USB0-ID: U100.M17 (PB7)
USBA-D+: U100.C13 (DDP); also elsewhere on the board
USBA-D-: U100.D13 (DDM); also elsewhere on the board
USBB-D+: U100.E14 (HDPA); also elsewhere on the board
USBB-D-: U100.E15 (HDMA); also elsewhere on the board
USBC-D+: U100.D14 (HDPB); also elsewhere on the board
USBC-D-: U100.C14 (HDMB); also elsewhere on the board
USB_DET: U100.T17 (PA27); also elsewhere on the board
VDD-IO: U100.F15 (BMS); also elsewhere on the board
WKUP: U100.B17 (WKUP); also elsewhere on the board
dq16: U100.J4 (PC16); also elsewhere on the board
dq17: U100.J2 (PC17); also elsewhere on the board
dq18: U100.H1 (PC18); also elsewhere on the board
dq19: U100.J1 (PC19); also elsewhere on the board
dq20: U100.K2 (PC20); also elsewhere on the board
dq21: U100.K4 (PC21); also elsewhere on the board
dq22: U100.M4 (PC22); also elsewhere on the board
dq23: U100.N3 (PC23); also elsewhere on the board
dq24: U100.K1 (PC24); also elsewhere on the board
dq25: U100.L3 (PC25); also elsewhere on the board
dq26: U100.L2 (PC26); also elsewhere on the board
dq27: U100.N4 (PC27); also elsewhere on the board
dq28: U100.P4 (PC28); also elsewhere on the board
dq29: U100.R3 (PC29); also elsewhere on the board
dq30: U100.P3 (PC30); also elsewhere on the board
dq31: U100.M2 (PC31); also elsewhere on the board
~RST: U100.G15 (NRST); also elsewhere on the board

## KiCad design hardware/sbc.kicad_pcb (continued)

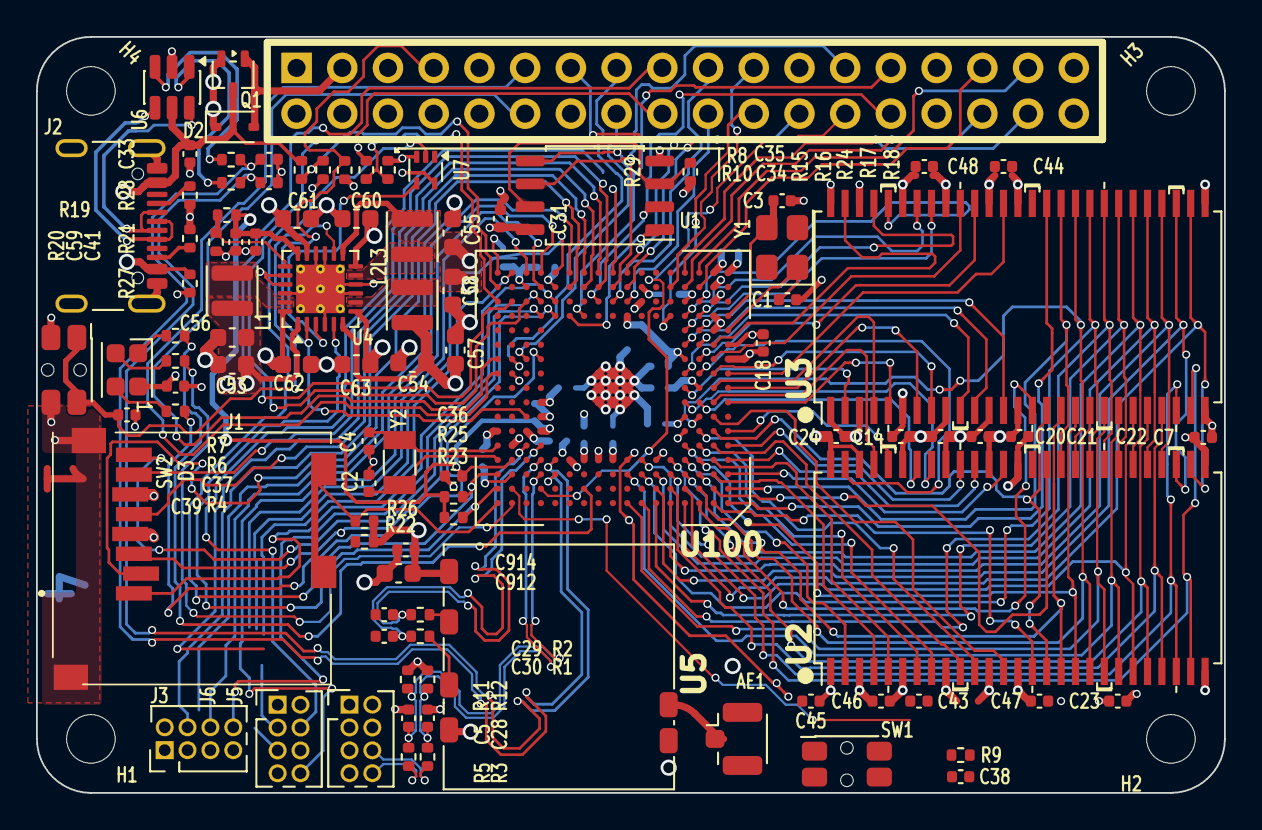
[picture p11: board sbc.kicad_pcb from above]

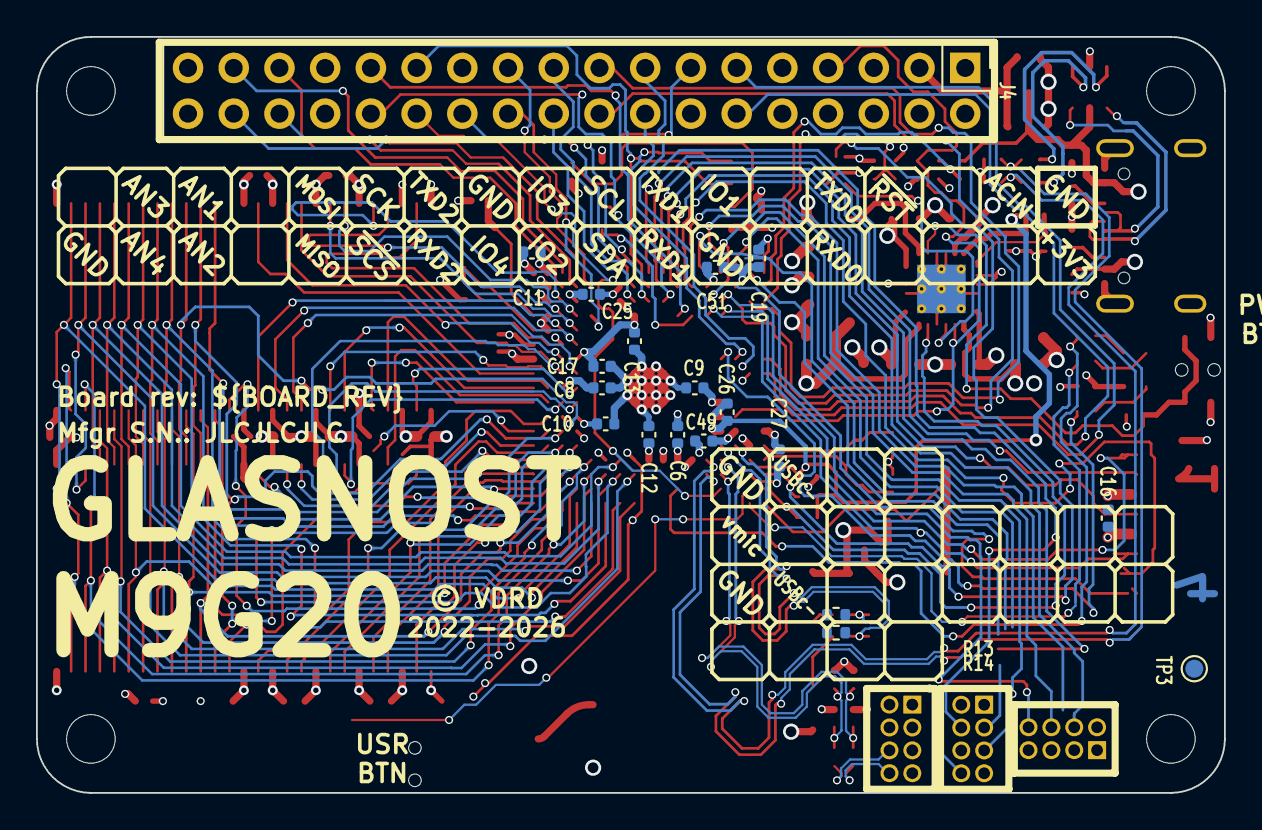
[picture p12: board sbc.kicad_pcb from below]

Board: 4 copper layers, 66.0 x 42.0 mm, 118 parts (19 on the bottom side), 143 nets.

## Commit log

2019-05-10 project: structure bringup
    [module_bga.brd, module_bga.sch]
2019-05-13 board: defined floorplan
    [module.brd, module.sch]
2019-05-13 layout: added bga sdram variant
    [module.brd, module.sch, module_bga.brd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]
2021-02-24 design: sdram connections defined
    [module.brd, module.sch]
2021-11-30 kicad bringup
    [cpu.kicad_sch, ethernet.kicad_sch, io.kicad_sch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]
2021-12-05 added decoupling caps
    [cpu.kicad_sch, io.kicad_sch, power.kicad_sch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]
2021-12-07 define cpu nets
    [cpu.kicad_sch, io.kicad_sch, power.kicad_sch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]
2021-12-08 small fixes
    [io.kicad_sch, sbc.kicad_pcb, sbc.kicad_sch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]
2021-12-13 more sdram routing
    [sbc.kicad_pcb]
2022-01-03 add preliminary board render
2022-01-04 rearranged components
    [cpu.kicad_sch, io.kicad_sch, power.kicad_sch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]
2022-01-13 added nor flash
    [sbc.kicad_pcb]
2022-01-14 repositioned components on board, added nor storage
    [cpu.kicad_sch, sbc.kicad_sch, sdcard.kicad_sch]
2022-01-16 add layer identification labels
    [sbc.kicad_pcb]
2022-03-09 fix usb connector
    [sbc.kicad_pcb]
2022-03-24 fix project structure
    [cpu.kicad_sch, power.kicad_sch, sbc.kicad_pcb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]
2022-03-30 fix sdram wire width
    [sbc.kicad_pcb]
2022-04-05 finish sdram
    [sbc.kicad_pcb]
2022-04-05 small changes
    [sbc.kicad_pcb]
2022-04-07 swap pmic for mcp16501
    [cpu.kicad_sch, io.kicad_sch, power.kicad_sch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]
2022-04-07 upload new board preview
    [sbc.kicad_pcb]
2022-04-07 add power rails
    [cpu.kicad_sch, io.kicad_sch, power.kicad_sch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]
2022-04-07 add silk info
    [cpu.kicad_sch, power.kicad_sch, sbc.kicad_pcb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]
2022-04-15 fix spi bus
    [cpu.kicad_sch, io.kicad_sch, power.kicad_sch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]
2022-05-14 add usb esd
    [cpu.kicad_sch, io.kicad_sch, sbc.kicad_pcb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]
2022-05-15 more routing for rmii
    [power.kicad_sch, sbc.kicad_pcb, sbc.kicad_sch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]
2022-05-22 fix eth header for compatibility
    [io.kicad_sch, sbc.kicad_pcb]
2022-05-28 route rmii bus
    [power.kicad_sch, sbc.kicad_pcb, sbc.kicad_sch]
2022-05-28 define usb connector
    [io.kicad_sch, sbc.kicad_pcb]
2022-05-29 move bulk caps to input zone
    [sbc.kicad_pcb]
2022-05-29 fixed wrong pullup on SDIO bus
    [cpu.kicad_sch, io.kicad_sch, sbc.kicad_pcb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]
2022-06-16 new routing work
    [sbc.kicad_pcb]
2022-06-29 update project
    [sbc.kicad_pcb]
2022-07-11 prepare for fab release
    [cpu.kicad_sch, io.kicad_sch, sbc.kicad_pcb]
2024-05-13 bump format to kicad 8
    [cpu.kicad_sch, io.kicad_sch, power.kicad_sch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]
2024-05-21 bump to kicad 8
    [cpu.kicad_sch, sbc.kicad_pcb]
2024-08-05 updated silkscreen labels
    [sbc.kicad_pcb]
2024-10-28 added tps and cleaned silk
    [cpu.kicad_sch, power.kicad_sch, sbc.kicad_pcb]
2025-03-18 rework power delivery
    [cpu.kicad_sch, io.kicad_sch, power.kicad_sch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]
2025-03-18 reorg project structure
    [cpu.kicad_sch, ethernet.kicad_sch, io.kicad_sch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]
2025-07-25 added rounded tracks
    [power.kicad_sch, sbc.kicad_pcb, sdcard.kicad_sch]
2026-01-26 backport changes from other boards
    [cpu.kicad_sch, io.kicad_sch, power.kicad_sch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]
2026-01-26 updated board layout and project structure
    [cpu.kicad_sch, ethernet.kicad_sch, io.kicad_sch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]
2026-02-02 backport features
    [sbc.kicad_pcb, sdcard.kicad_sch]
2026-02-03 modified pmic layout
    [io.kicad_sch, power.kicad_sch, sbc.kicad_pcb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]
2026-02-03 more routing
    [cpu.kicad_sch, sbc.kicad_pcb, sdcard.kicad_sch]
2026-04-30 almost done for rev 2
    [cpu.kicad_sch, io.kicad_sch, power.kicad_sch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]
2026-05-02 updated gitignore
    [sbc.kicad_pcb]
2026-05-23 small routing for v2
    [sbc.kicad_pcb]
2026-05-23 cosmetics for rev2
    [io.kicad_sch, sbc.kicad_pcb, sbc.kicad_sch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]
2026-05-25 fix drc for rev2
    [io.kicad_sch]

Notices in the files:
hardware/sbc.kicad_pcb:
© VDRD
